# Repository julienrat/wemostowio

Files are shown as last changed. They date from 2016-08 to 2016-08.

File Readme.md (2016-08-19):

Wemos to Wio node
=
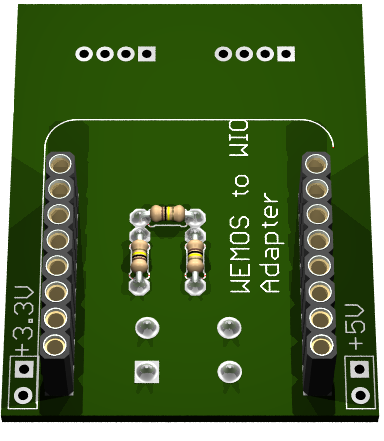
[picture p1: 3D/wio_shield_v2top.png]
 
----
##Principe
Ce tutoriel permet de convertir une carte Wemos en une carte compatible Wio Node. Et ainsi construire facilement des objets connectés.

###C'est quoi un Wio Node ?
Le Wio Node est une carte développée par Seeedstudio, basée sur un ESP8266 permettant de construire des petits appareils connectés à divers services tels que twitter, facebook, etc ...
La configuration du Wio Node se fait par un téléphone sous Android et via une application dédiée.

Pour plus d'informations, vous pouvez regarder la vidéo de présentation :
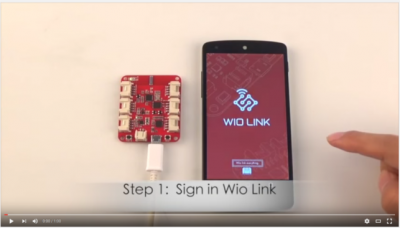
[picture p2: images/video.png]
(https://www.youtube.com/watch?v=N-13m8Lvzxs)


##Flasher le Wemos
### Récupérer le firmware Wio Node
[user1.bin](https://github.com/Seeed-Studio/Wio_Link/raw/master/users_build/local_user_00000000000000000000/user1.bin)

[user2.bin](https://github.com/Seeed-Studio/Wio_Link/raw/master/users_build/local_user_00000000000000000000/user2.bin)

[bootloader](http://www.seeedstudio.com/wiki/images/4/4b/Esp8266sdk1.4.1.zip)

Décompresser Bootloader et copier user1.bin, user2.bin, boot_v1.4(b1).bin, blank.bin et esp_init_data_default.bin dans le même repertoire
### Installer esptool 
Suivant votre distribution, vous pouvez trouver esptool dans vos dépots, ou le télécharger à cette adresse https://github.com/themadinventor/esptool

### Flasher le Wemos Sous Linux

```shell
esptool -p /dev/ttyUSB0 -b 230400 write_flash --flash_size 32m-c1 0x0000 boot_v1.4\(b1\).bin 0x1000 user1.bin 0x101000 user2.bin 0x3fc000 esp_init_data_default.bin 0x3fe000 blank.bin

```
### Flasher le Wemos Sous Windows
Il vous faudra un utilitaire de flashage pour Windows disponibla à cette adresse : (http://bbs.espressif.com/download/file.php?id=856)

Puis configurez le logiciel comme ci-dessous

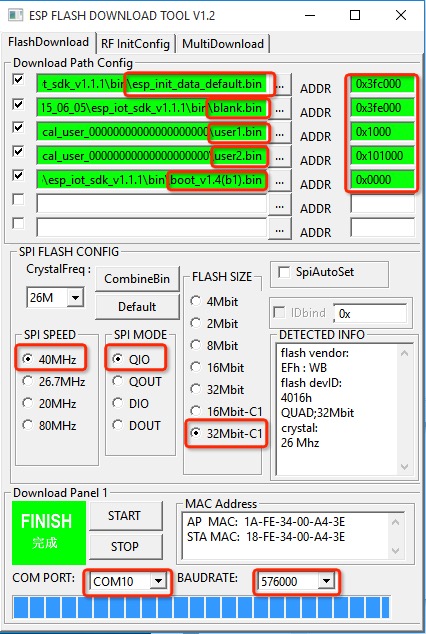
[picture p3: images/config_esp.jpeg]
config


## Installer l'application Android
https://play.google.com/store/apps/details?id=cc.seeed.iot.ap

## Utilisation // Configuration
###Configuration
- Appuyer sur le bouton fonction 4 secondes afin de mettre le wemos en mode "Configuration". La led arrete de clignoter et effectue un "fading".
- Démarrer l'application Wio sur le téléphone.

Description | Screenshot
---------|---------
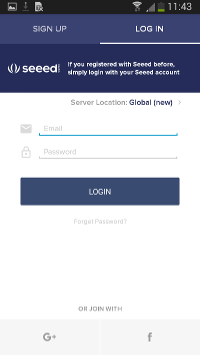
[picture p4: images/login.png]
login
Connectez vous ou créez un compte |  
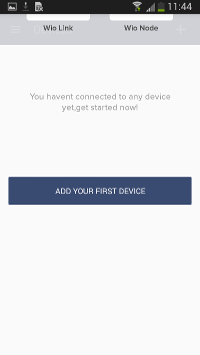
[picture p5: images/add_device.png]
add_device
Ajoutez votre Wemos, et choisissez Wio Node |  
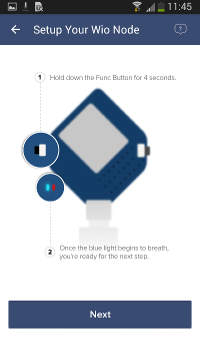
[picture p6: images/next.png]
App
Assurez-vous que la led bleue effectue un "fading", sinon appuyez 4 sec sur le bouton Fonction | 
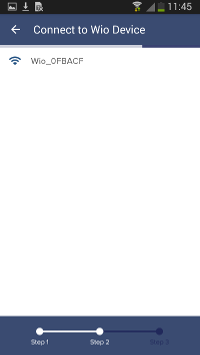
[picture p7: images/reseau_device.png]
selection local network
Connectez vous au wemos, il devrait apparaitre dans la liste | 
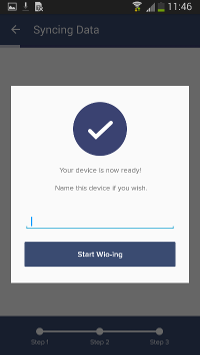
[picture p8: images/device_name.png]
name
Choisissez un nom pour votre Wemos | 
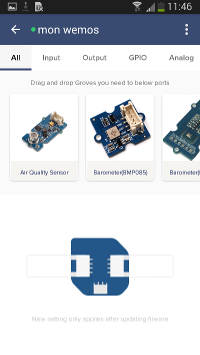
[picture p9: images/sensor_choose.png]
sensor
Choisissez le capteur que vous souhaitez connecter au wemos | 
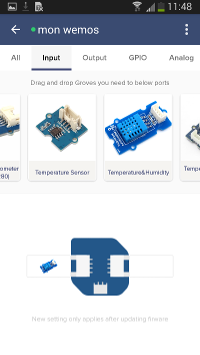
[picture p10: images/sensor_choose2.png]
sensor2
A l'aide d'un drag'n'drop glissez le capteur sur un connecteur de votre choix | 
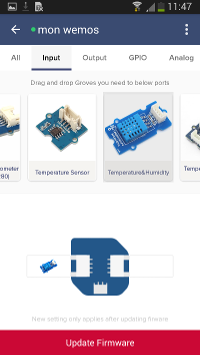
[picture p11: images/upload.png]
upload
Cliquez sur "Update Firmware" pour envoyer la nouvelle configuration au wemos | 

Voilà, votre wemos est opérationel, il ne reste plus qu'à le connecter à un canal de diffusion, ici c'est le canal de diffusion IFTTT que nous alons choisir.

###Utilisation simple
Pour l'instant Un seul canal est disponible pour wio : IFTTT 

Ce service, apres inscription permet de relier nos capteurs à une multitude de services tels que Twitter, Facebook et même les lamps connectées de chez philips .. etc.

Le principe est simple IF This Then That.(Si Ceci Alors Cela) et se présente sous la forme de recettes : Le site [IFTTT](https://ifttt.com)

Par exemple :
Un tweet quand il fait chaud :
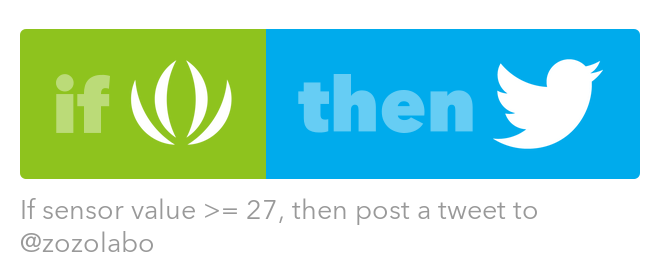
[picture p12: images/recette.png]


On peux aussi connecter IFTTT à la platteforme IO d'adafruit

[Recette IFTTT](https://ifttt.com/recipes/452996-temperature-data-viz)| [DashBoard Adafruit](https://io.adafruit.com/ratjulien/welcome-dashboard)
---------|---------
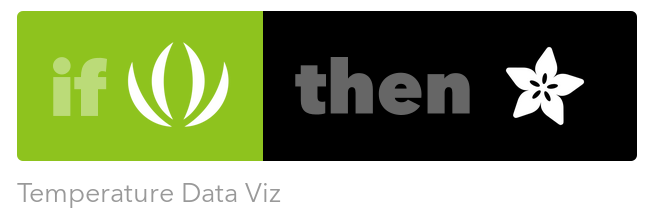
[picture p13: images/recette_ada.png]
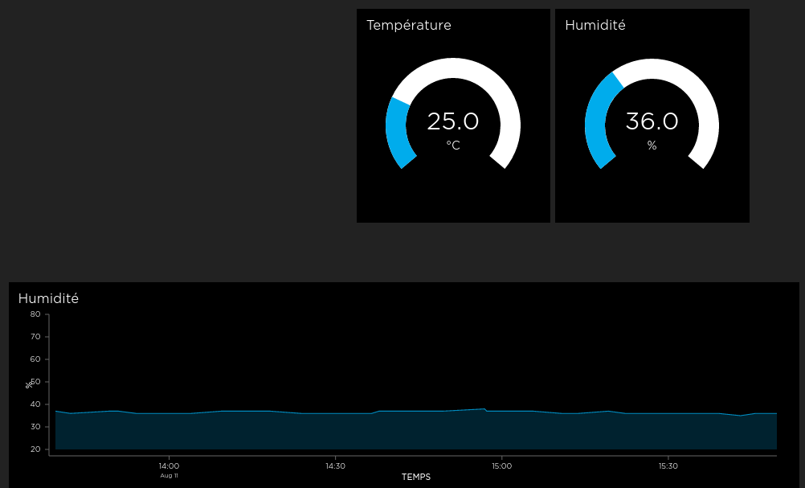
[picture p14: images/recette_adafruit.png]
 |  

###Schéma de câblage
[Fritzing](/schema/wemos_wio_sch.fzz)| Eagle
---------|---------
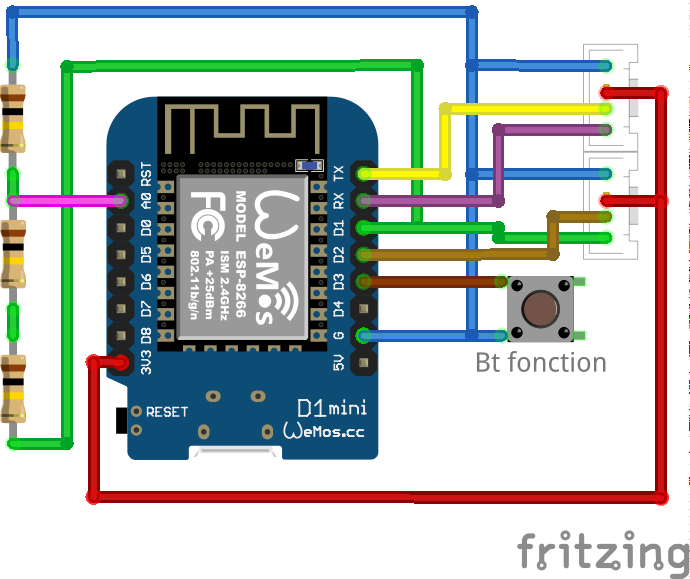
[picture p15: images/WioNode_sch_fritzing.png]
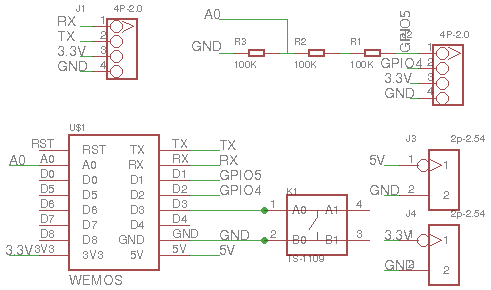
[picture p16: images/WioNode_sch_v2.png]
 |  

###Vue PCB
Top | Bottom 
---------|---------
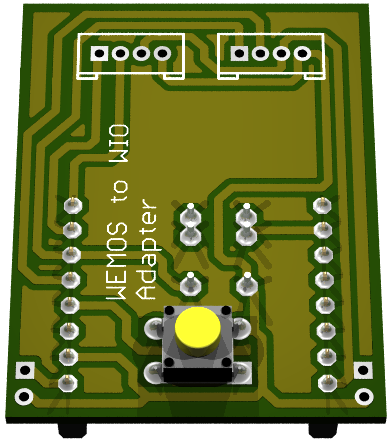
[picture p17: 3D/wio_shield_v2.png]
selection |  

###Production
Typon | [Plaque d'essais](/schema/wemos_wio_plaque_essais.fzz)
---------|---------
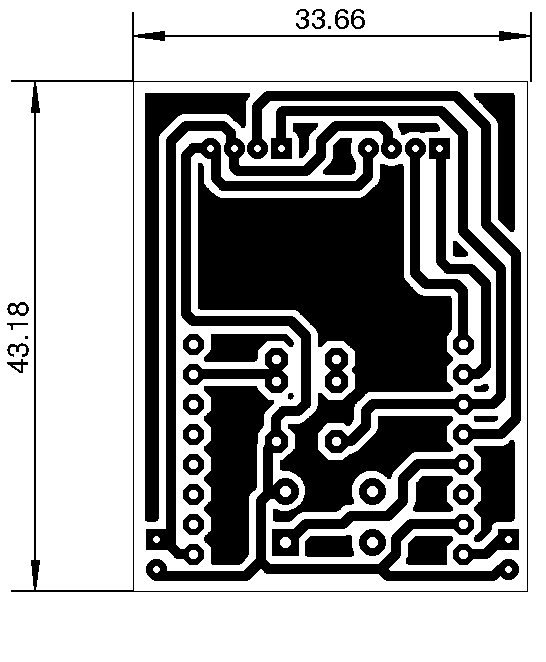
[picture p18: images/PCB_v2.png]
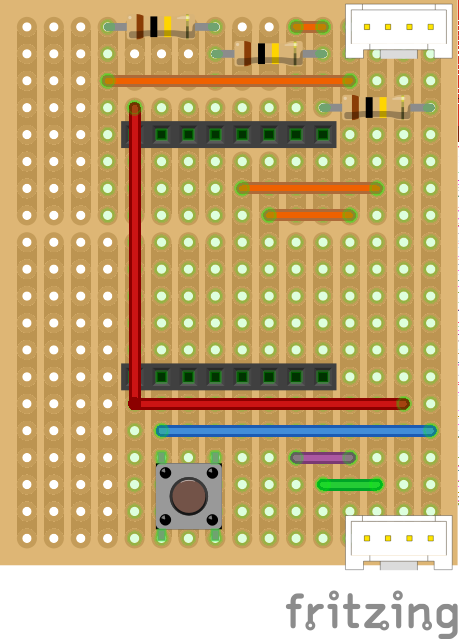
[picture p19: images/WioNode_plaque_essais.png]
 |  

##Sources
Ce projet est sous licence CCbySA

Ressources seeedstudio : 
- https://github.com/Seeed-Studio/Wio_Link/wiki/Advanced%20User%20Guide
- https://github.com/Seeed-Studio/Wio_Link

Ressources Wemos
- http://www.wemos.cc/

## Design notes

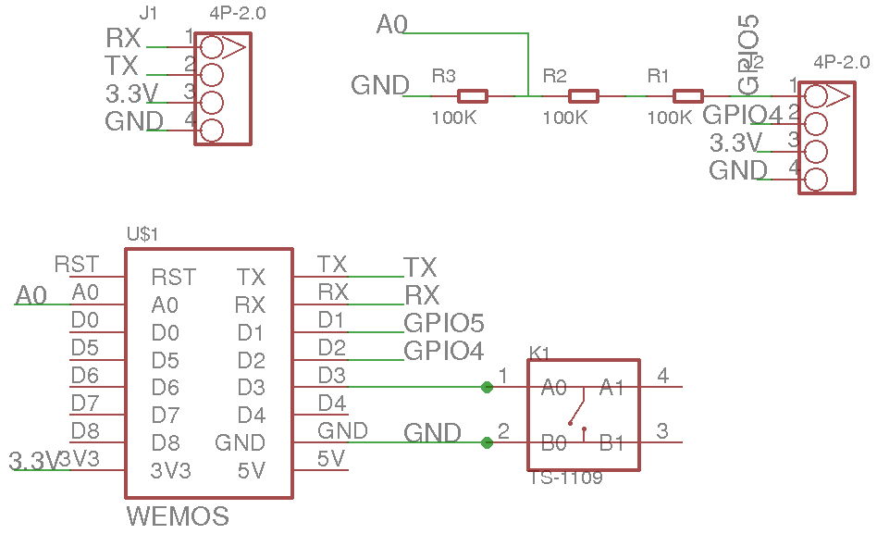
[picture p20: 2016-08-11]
images/WioNode_sch.png

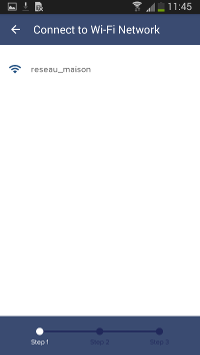
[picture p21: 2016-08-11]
images/reseau_local.png

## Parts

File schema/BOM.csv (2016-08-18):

Parts/Designator | Seeed SKU/ Mfr. Part # | Quantity
J1 | 320110033 | 1
J2 | 320110033 | 1
K1 | 311020024 | 1
R1 | 301020040 | 1
R2 | 301020040 | 1
R3 | 301020040 | 1
U$1 | 3460590P1 | 2

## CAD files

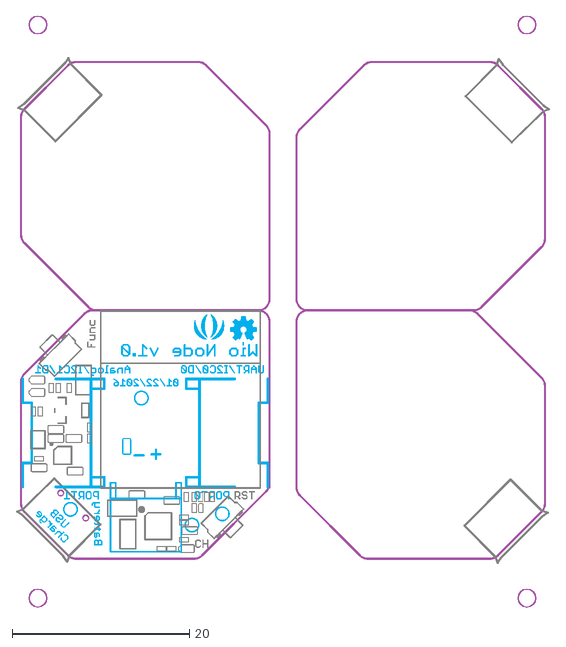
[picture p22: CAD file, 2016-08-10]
ressources/Wio Node Schematics/Wio Node v1.0.dxf
60.3 x 66.8

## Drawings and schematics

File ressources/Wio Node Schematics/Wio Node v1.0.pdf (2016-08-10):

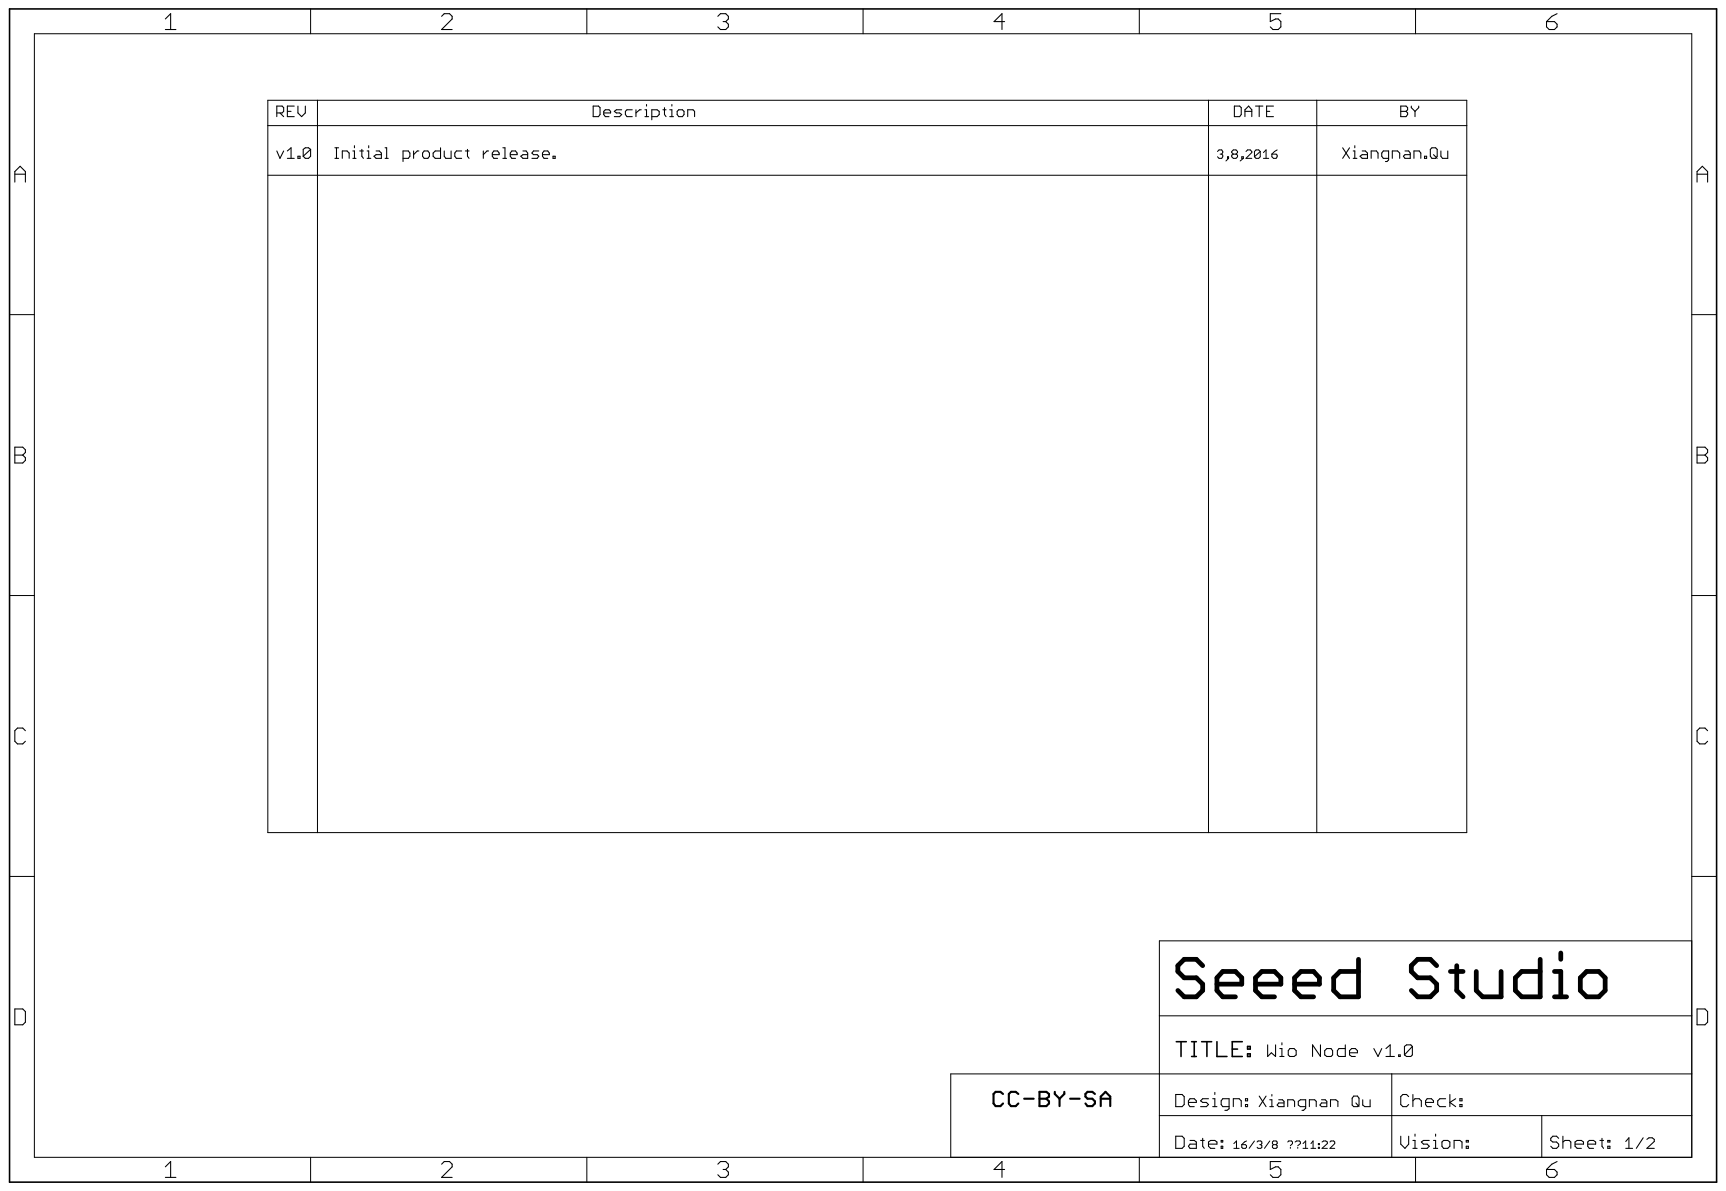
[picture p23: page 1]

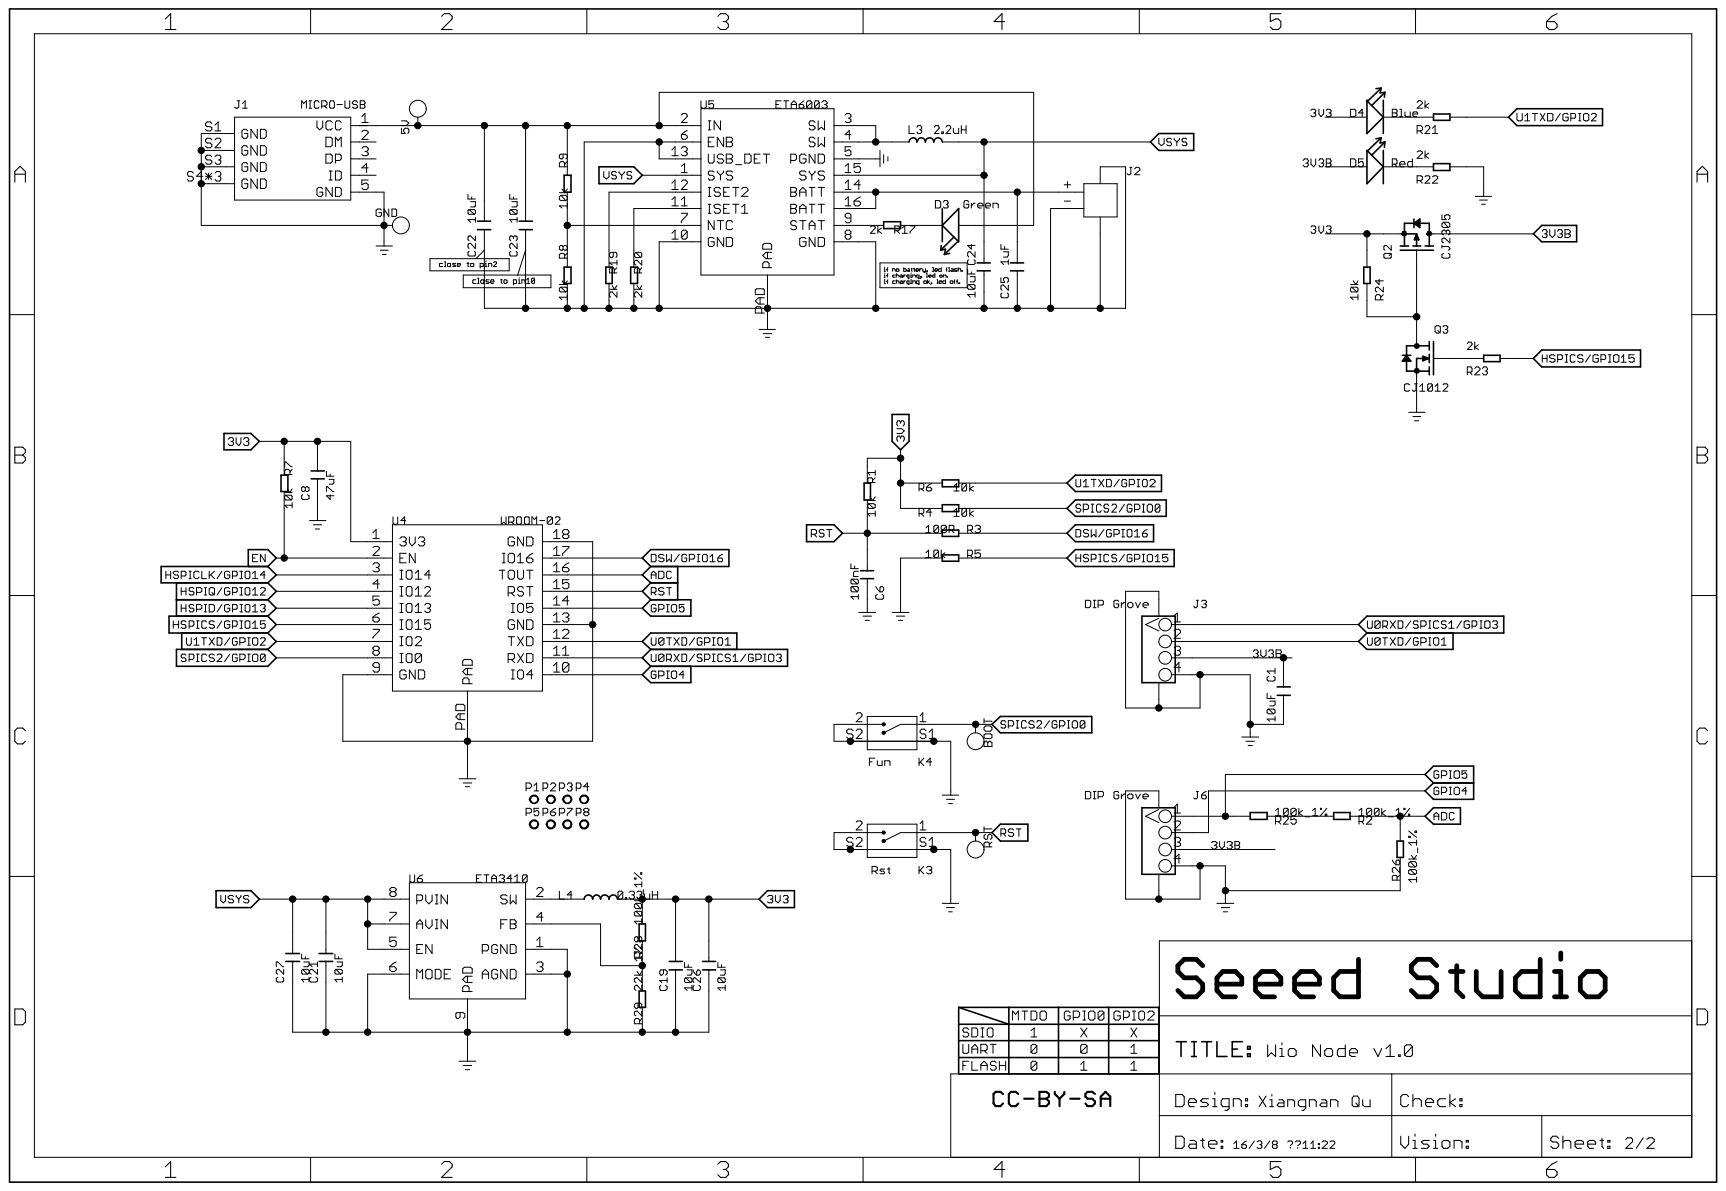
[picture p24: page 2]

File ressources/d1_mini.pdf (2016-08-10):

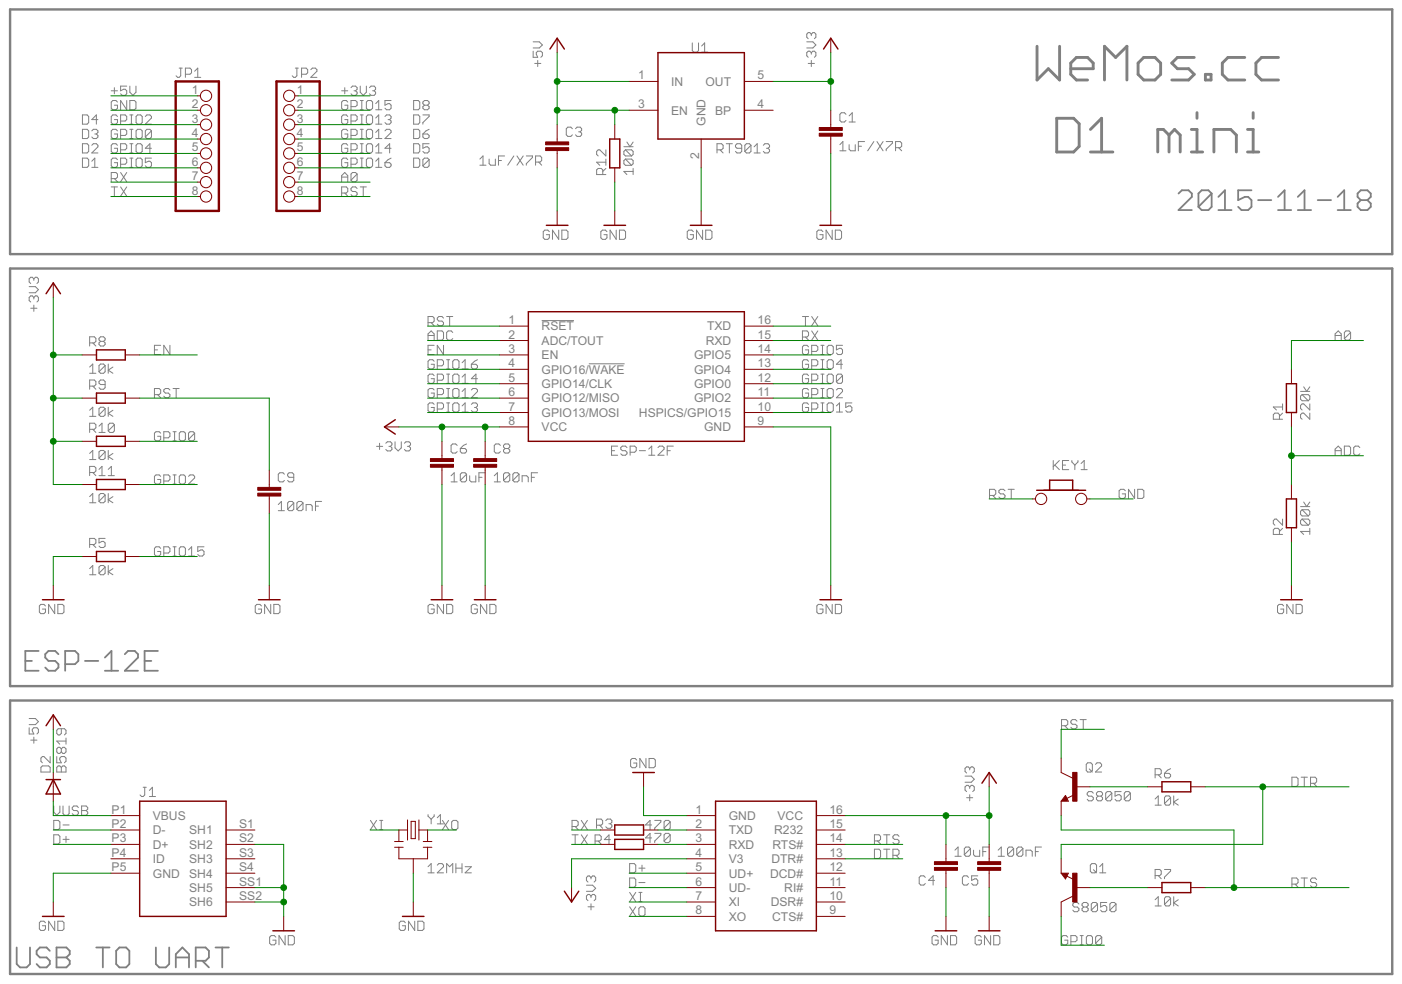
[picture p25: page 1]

14 RXD
13 GPIO5

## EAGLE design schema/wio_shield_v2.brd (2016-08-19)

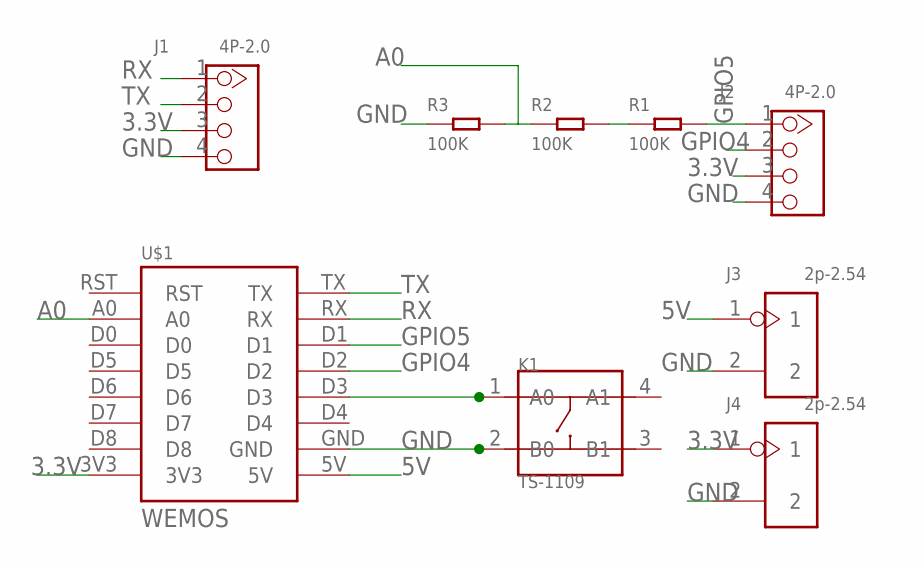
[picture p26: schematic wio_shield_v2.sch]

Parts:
J1, J2: 4P-2.0; HW4-2.0
J3, J4: 2p-2.54; H2-2.54
K1: TS-1109; SW4-6.0X6.0X5.0MM
R1, R2, R3: 100K; PR-D1.8*L3.3MM
U$1: WEMOS

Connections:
3.3V: J1.3, J2.3, J4.1, U$1.3V3
5V: J3.1, U$1.5V
A0: R2.6 (1), R3.5 (2), U$1.A0
GND: J1.4, J2.4, J3.2, J4.2, K1.2 (B0), R3.6 (1), U$1.GND
GPIO4: J2.2, U$1.D2
GPIO5: J2.1, R1.5 (2), U$1.D1
unnamed: R1.6 (1), R2.5 (2)
unnamed: K1.1 (A0), U$1.D3
RX: J1.1, U$1.RX
TX: J1.2, U$1.TX

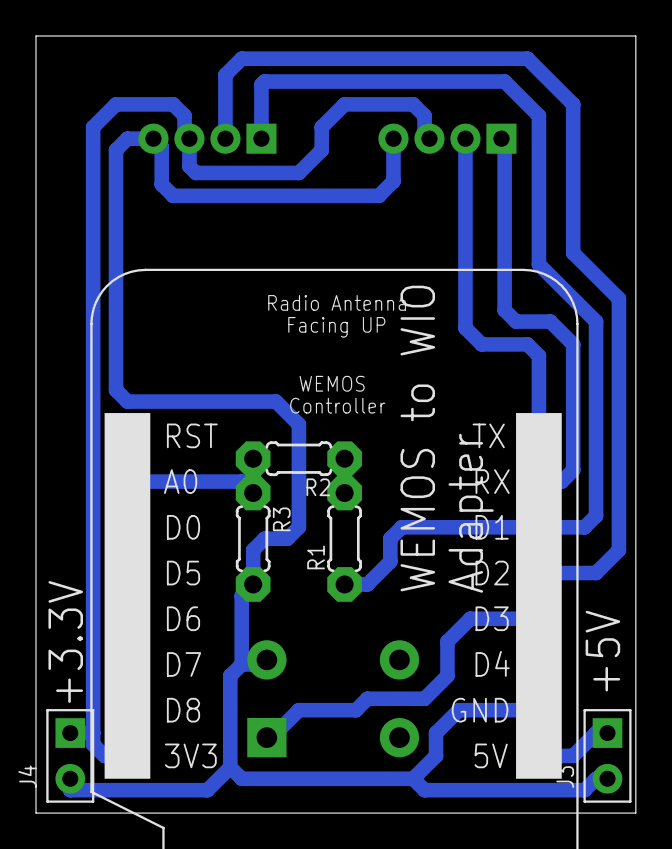
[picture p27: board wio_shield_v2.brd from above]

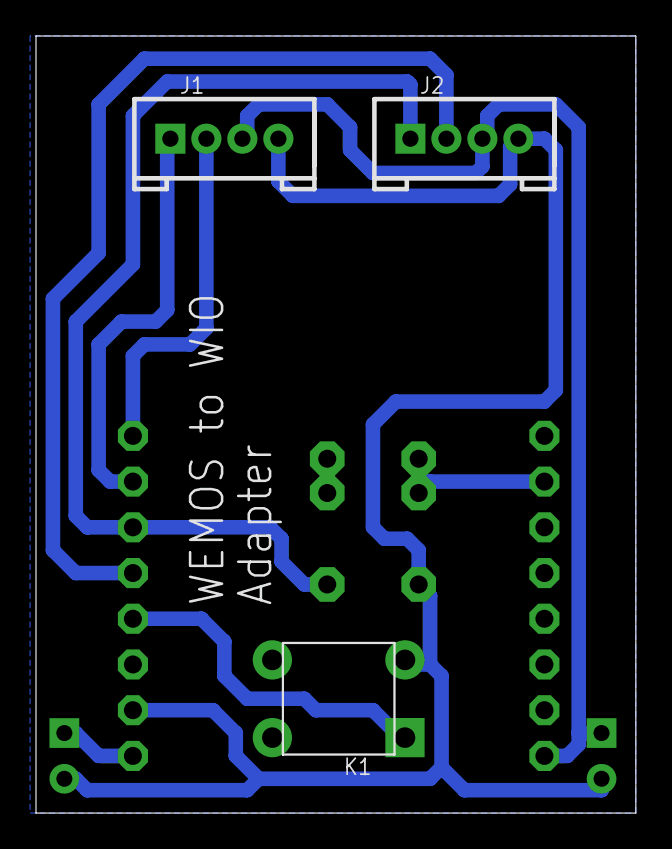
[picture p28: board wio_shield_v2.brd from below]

Board: 2 copper layers, 33.3 x 43.2 mm, 9 parts (3 on the bottom side), 10 nets.

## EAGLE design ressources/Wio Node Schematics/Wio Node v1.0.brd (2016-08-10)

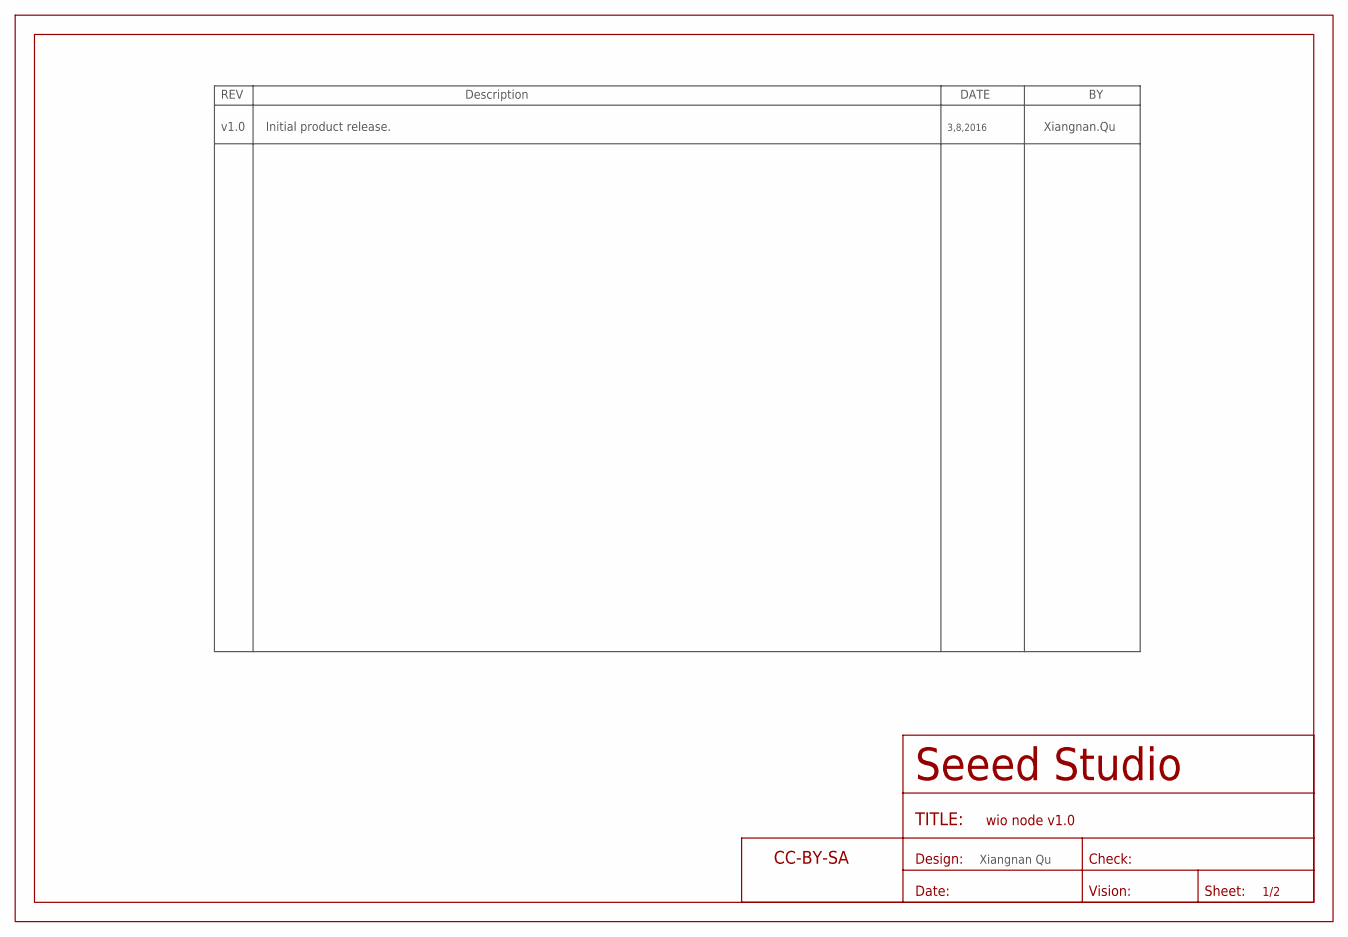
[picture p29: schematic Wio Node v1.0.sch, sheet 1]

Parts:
FR4: SEEEDSTUDIO-OPEN-SCH-FRAME; SEEEDSTUDIO-PCB-FRAME

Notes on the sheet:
v1.0
Initial product release.
3,8,2016
Xiangnan.Qu
Xiangnan Qu

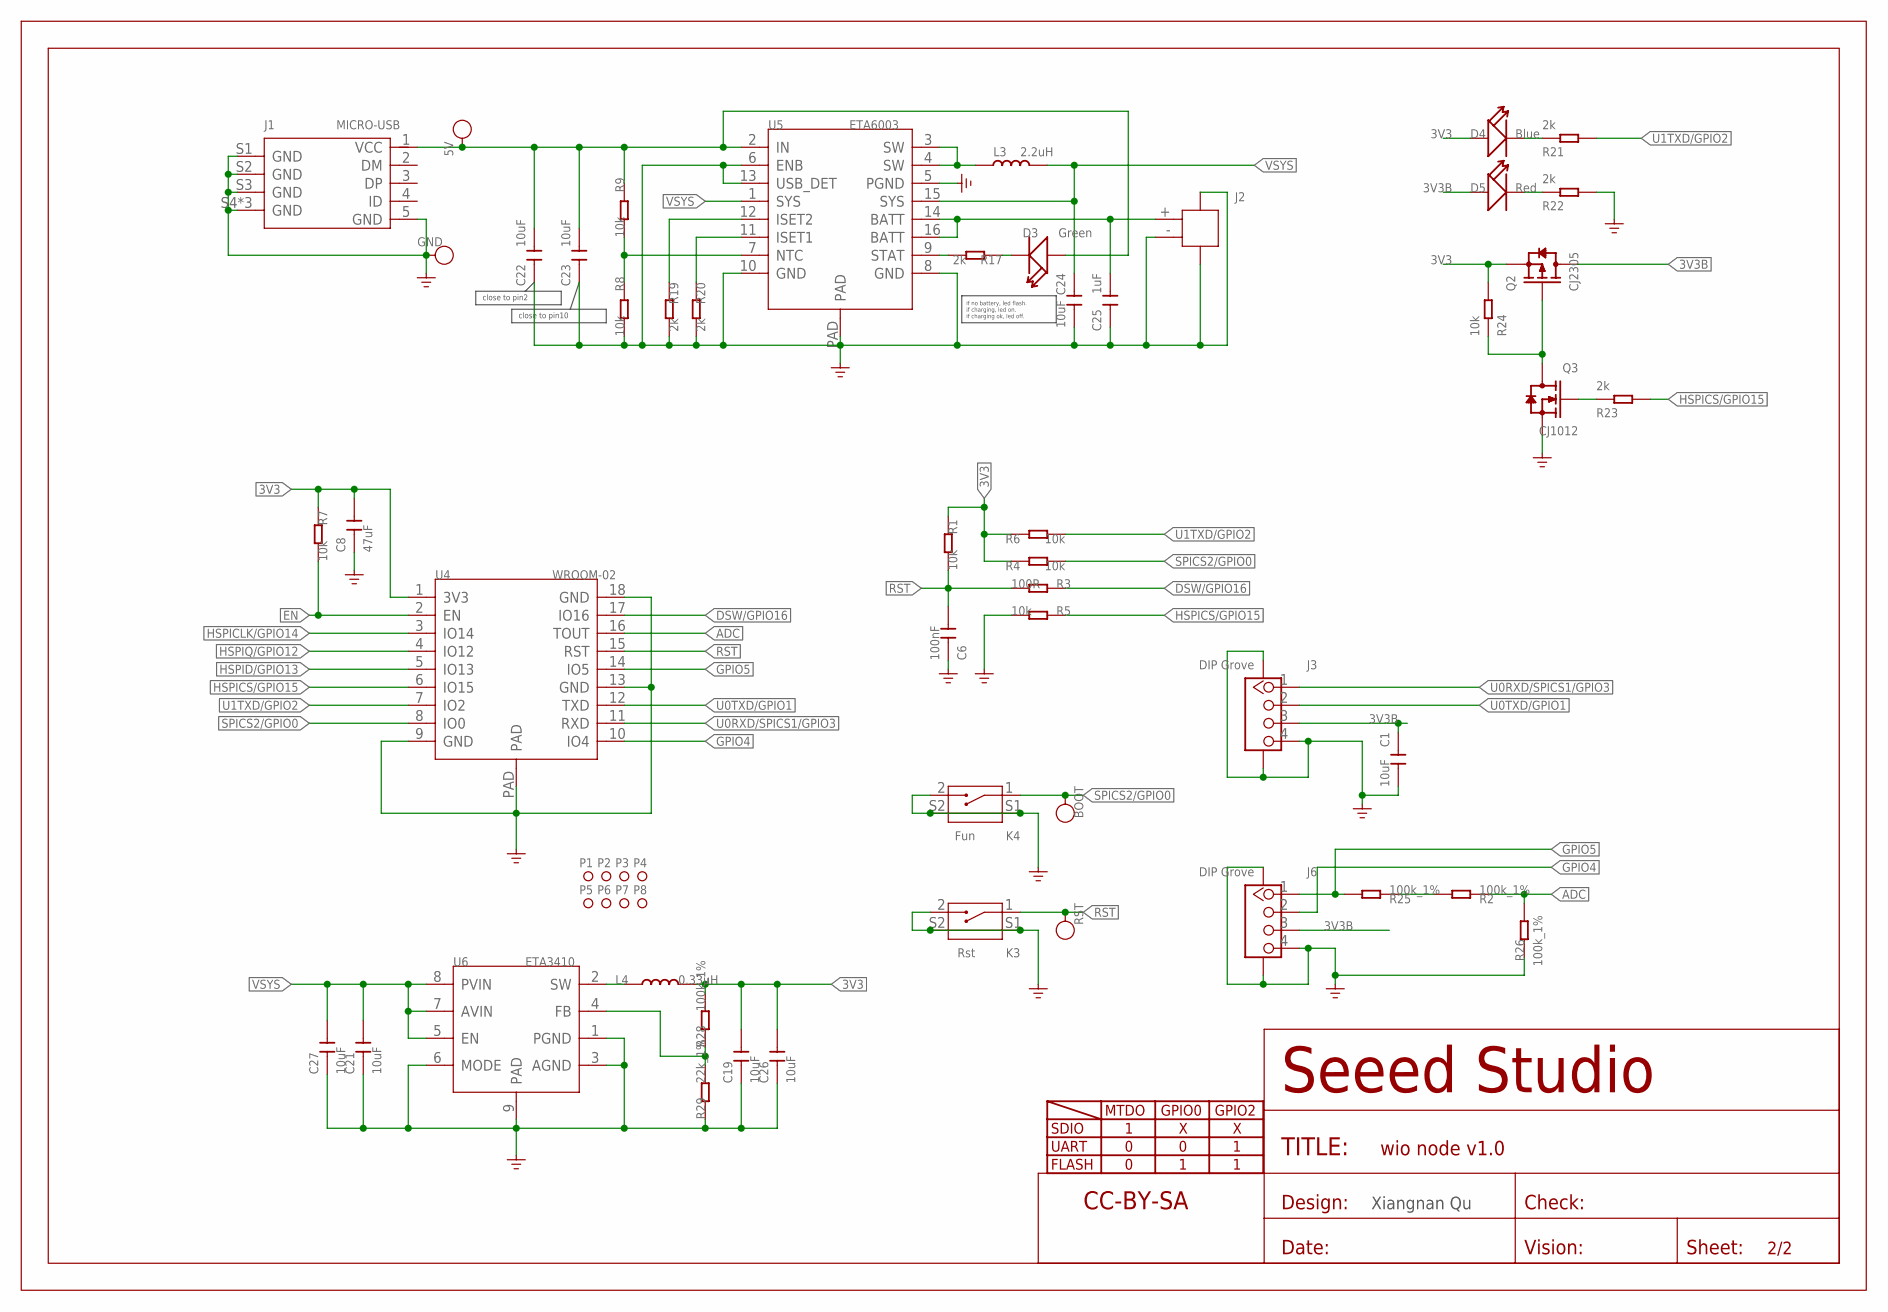
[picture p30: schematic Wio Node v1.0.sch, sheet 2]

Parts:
5V: TEST-POINT'4545'; TP-D45MIL
BOOT: TEST-POINT'4545'; TP-D45MIL
C1, C19, C21, C23, C24, C26, C27: 10uF; C0402
C6: 100nF; C0201
C8: 47uF; C0805
C22: 10uF; C0805
C25: 1uF; C0402
D3: Green; LED-0402
D4: Blue; LED-0402
D5: Red; LED-0402
FR1: SEEEDSTUDIO-OPEN-SCH-FRAME; SEEEDSTUDIO-PCB-FRAME
GND: TEST-POINT'4545'; TP-D45MIL
J1: MICRO-USB; MICRO-USB5+4P-SMD-0.65-B
J2: JST-2P-SMD'2.0'; HW2-SMD-2.0-90D
J3, J6: DIP Grove; HW4-SMD-2.0-90D
K3: Rst; SW4-SMD-4.5X3.8X1.8MM-90D
K4: Fun; SW4-SMD-4.5X3.8X1.8MM-90D
L3: 2.2uH; L0805
L4: 0.33uH; L201610
P1, P2, P3, P4, P5, P6, P7, P8: MARK-1.0'ANNULAR'; ROUND-MARK-1.0
Q2: CJ2305; SOT-23
Q3: CJ1012; SOT-523
R1, R4, R5, R6, R7, R8, R9, R24: 10k; R0201
R2, R25, R26, R28: 100k_1%; R0201
R3: 100R; R0201
R17, R19, R20, R21, R22, R23: 2k; R0201
R29: 22k_1%; R0402
RST: TEST-POINT'4545'; TP-D45MIL
U4: WROOM-02; ESP18-SMD-1.5-18X20MM
U5: ETA6003; QFN16G-0.5-3X3MM
U6: ETA3410; DFN8G-0.5-2X2MM

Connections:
3V3: C8.2, C19.2, C26.2, D4.+, L4.2, Q2.2 (S), R1.1, R4.1, R6.1, R7.1, R24.2, R28.2, U4.1 (3V3)
3V3B: C1.1, D5.+, J3.3, J6.3, Q2.3 (D)
ADC: R2.1, R26.2, U4.16 (TOUT)
DSW/GPIO16: R3.1, U4.17 (IO16)
EN: R7.2, U4.2 (EN)
GND: C1.2, C6.1, C8.1, C19.1, C21.1, C22.2, C23.2, C24.2, C25.2, C26.1, C27.1, GND.T, J1.5 (GND), J1.S1 (GND), J1.S2 (GND), J1.S3 (GND), J1.S4 (GND), J1.S5 (GND), J1.S6 (GND), J2.3, J2.4, J2.- (2), J3.4, J3.SS1, J3.SS2, J6.4, J6.SS1, J6.SS2, K3.2, K3.S1, K3.S2, K4.2, K4.S1, K4.S2, Q3.2 (S), R5.2, R8.2, R19.2, R20.2, R22.2, R26.1, R29.1, U4.9 (GND), U4.13 (GND), U4.18 (GND), U4.PAD, U5.5 (PGND), U5.6 (ENB), U5.8 (GND), U5.10 (GND), U5.13 (USB_DET), U5.PAD, U6.1 (PGND), U6.3 (AGND), U6.6 (MODE), U6.9 (PAD)
GPIO4: J6.2, U4.10 (IO4)
GPIO5: J6.1, R25.2, U4.14 (IO5)
HSPICLK/GPIO14: U4.3 (IO14)
HSPICS/GPIO15: R5.1, R23.2, U4.6 (IO15)
HSPID/GPIO13: U4.5 (IO13)
HSPIQ/GPIO12: U4.4 (IO12)
unnamed: R2.2, R25.1
unnamed: R8.1, R9.2, U5.7 (NTC)
unnamed: Q2.1 (G), Q3.3 (D), R24.1
unnamed: Q3.1 (G), R23.1
unnamed: D4.-, R21.1
unnamed: D5.-, R22.1
unnamed: L3.1, U5.3 (SW), U5.4 (SW)
unnamed: C25.1, J2.+ (1), U5.14 (BATT), U5.16 (BATT)
unnamed: L4.1, U6.2 (SW)
unnamed: D3.-, R17.1
unnamed: R17.2, U5.9 (STAT)
unnamed: R28.1, R29.2, U6.4 (FB)
unnamed: R20.1, U5.11 (ISET1)
unnamed: R19.1, U5.12 (ISET2)
RST: C6.2, K3.1, R1.2, R3.2, RST.T, U4.15 (RST)
SPICS2/GPIO0: BOOT.T, K4.1, R4.2, U4.8 (IO0)
U0RXD/SPICS1/GPIO3: J3.1, U4.11 (RXD)
U0TXD/GPIO1: J3.2, U4.12 (TXD)
U1TXD/GPIO2: R6.2, R21.2, U4.7 (IO2)
VSYS: C21.2, C24.1, C27.2, L3.2, U5.1 (SYS), U5.15 (SYS), U6.5 (EN), U6.7 (AVIN), U6.8 (PVIN)
VUSB: 5V.T, C22.1, C23.1, D3.+, J1.1 (VCC), R9.1, U5.2 (IN)

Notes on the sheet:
SDIO
UART
FLASH
MTDO
GPIO0
GPIO2
Xiangnan Qu
close to pin10
if no battery, led flash. if charging, led on. if charging ok, led off.
close to pin2

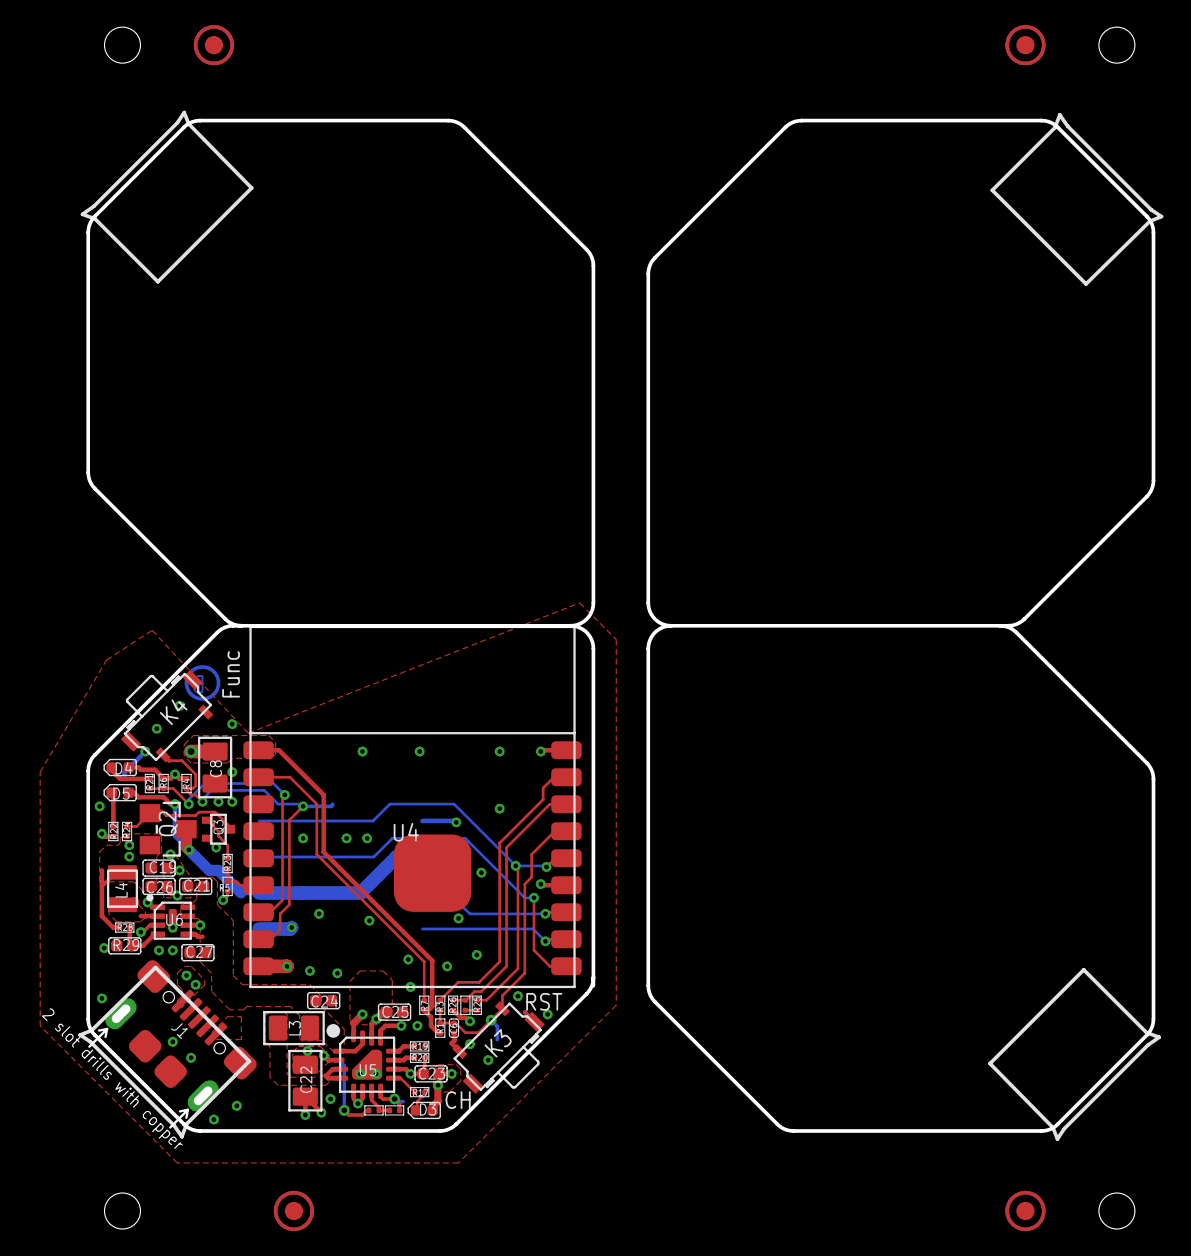
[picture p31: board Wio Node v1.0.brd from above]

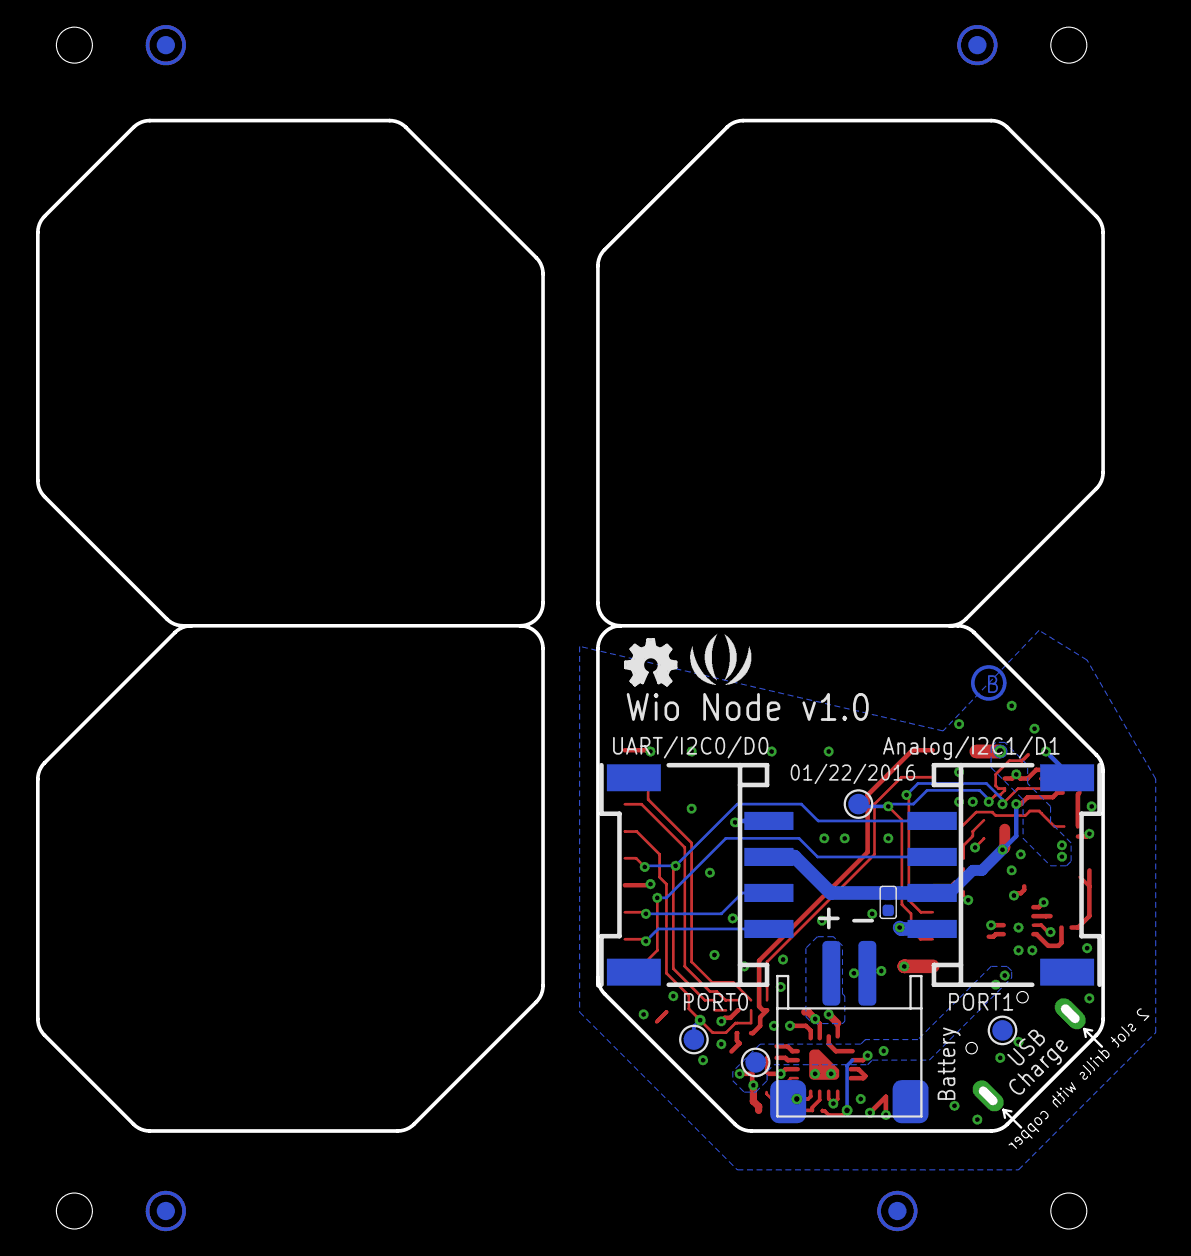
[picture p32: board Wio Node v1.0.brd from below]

Board: 2 copper layers, 28.1 x 56.1 mm, 63 parts (14 on the bottom side), 30 nets.

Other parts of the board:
U$2: OSHW_FILLX100_NOTEXT
U$3: SEEED-SILK-160*153MIL

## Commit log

2016-08-10 + ‘.sparkleshare’ + ‘SparkleShare.txt’
2016-08-10 + ‘3D/’ + ‘3D/wio_shield.png’ + ‘3D/wio_shield.pov’ + ‘3D/wio_shield.pov.none.txt’ + ‘3D/wio_shield.sh’ + ‘3D/wio_shield_top.png’ + ‘eagle.epf’ + ‘ressources/Wio Node Schematics/Wio Node v1.0.brd’ + 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
    [Wio Node v1.0.brd, Wio Node v1.0.dxf, Wio Node v1.0.sch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]
2016-08-10 / ‘3D/wio_shield_top.png’
2016-08-10 / ‘3D/wio_shield.png’
2016-08-11 - ‘3D/wio_shield.pov.none.txt’
2016-08-11 - ‘3D/wio_shield.pov’ - ‘3D/wio_shield.sh’
2016-08-11 - ‘eagle.epf’ - ‘wio_shield.b##’ - ‘wio_shield.b#1’ - ‘wio_shield.b#2’ - ‘wio_shield.s#1’ - ‘wio_shield.s#2’ - ‘wio_shield.s#3’
2016-08-11 + ‘Schema/’
2016-08-11 < ‘Schema/’ > ‘schema/’
2016-08-11 < ‘wio_shield.brd’ > ‘schema/wio_shield.brd’ < ‘wio_shield.sch’ > ‘schema/wio_shield.sch’ - ‘wio_shield.mpd’
    [wio_shield.brd, wio_shield.sch]
2016-08-11 + ‘Readme.md’
2016-08-11 / ‘Readme.md’
2016-08-11 + ‘images/’
2016-08-11 + ‘images/video.png’
2016-08-11 + ‘images/WioNode_plaque_essais.png’
2016-08-11 + ‘images/WioNode_sch.png’
2016-08-11 / ‘images/WioNode_plaque_essais.png’
2016-08-11 + ‘schema/.wio_shield.brd.lck’ + ‘schema/.wio_shield.sch.lck’ + ‘schema/wio_shield.b#1’ / ‘schema/wio_shield.brd’ + ‘schema/wio_shield.s#1’ / ‘schema/wio_shield.sch’
2016-08-11 + ‘images/PCB.png’
2016-08-11 + ‘images/WioNode_sch_fritzing.png’
2016-08-11 + ‘schema/wemos_wio_sch.fzz’
    [wemos_wio_sch.fzz]
2016-08-11 + ‘schema/wemos_wio_plaque_essais.fzz’
    [wemos_wio_plaque_essais.fzz]
2016-08-11 / ‘schema/wemos_wio_sch.fzz’
    [wemos_wio_sch.fzz]
2016-08-11 / ‘images/WioNode_sch_fritzing.png’
2016-08-11 - ‘schema/.wio_shield.brd.lck’ - ‘schema/.wio_shield.sch.lck’
2016-08-11 - ‘schema/wio_shield.b#1’ - ‘schema/wio_shield.s#1’
2016-08-11 + ‘images/add_device.png’ + ‘images/device_name.png’ + ‘images/login.png’ + ‘images/next.png’ + ‘images/reseau_device.png’ + ‘images/reseau_local.png’ + ‘images/sensor_choose.png’ + ‘images/sensor_ch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
2016-08-11 / ‘images/upload.png’
2016-08-11 / ‘images/sensor_choose2.png’
2016-08-11 / ‘images/sensor_choose.png’
2016-08-11 / ‘images/reseau_local.png’
2016-08-11 / ‘images/reseau_device.png’
2016-08-11 / ‘images/next.png’
2016-08-11 / ‘images/login.png’
2016-08-11 / ‘images/device_name.png’
2016-08-11 / ‘images/add_device.png’
2016-08-11 + ‘images/recette.png’
2016-08-11 + ‘images/recette_adafruit.png’
2016-08-11 + ‘images/recette_ada.png’
2016-08-18 + ‘schema/BOM.csv’
    [BOM.csv]
2016-08-18 / ‘schema/BOM.csv’
    [BOM.csv]
2016-08-18 + ‘images/config_esp.jpeg’
2016-08-19 + ‘3D/wio_shield_v2.png’ + ‘3D/wio_shield_v2top.png’
2016-08-19 + ‘schema/wio_shield_v2.brd’ + ‘schema/wio_shield_v2.sch’
    [wio_shield_v2.brd, wio_shield_v2.sch]
2016-08-19 / ‘3D/wio_shield_v2.png’
2016-08-19 / ‘3D/wio_shield_v2top.png’
2016-08-19 + ‘images/WioNode_sch_v2.png’
2016-08-19 / ‘images/WioNode_sch_v2.png’
2016-08-19 < ‘images/WioNode_sch_v2.png’ > ‘images/PCB_v2.png’
2016-08-19 / ‘images/PCB_v2.png’

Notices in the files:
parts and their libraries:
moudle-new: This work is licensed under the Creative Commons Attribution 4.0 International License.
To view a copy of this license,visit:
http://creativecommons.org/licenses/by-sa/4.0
